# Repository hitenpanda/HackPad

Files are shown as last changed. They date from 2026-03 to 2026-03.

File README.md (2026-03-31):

# HackPad v1

A custom parametric mechanical macropad powered by the Seeed Studio XIAO RP2040. Designed, routed in KiCad, and modeled in Fusion 360 for the Hack Club Blueprint initiative.

## Images
### Overall Look
Overall

### Schematic
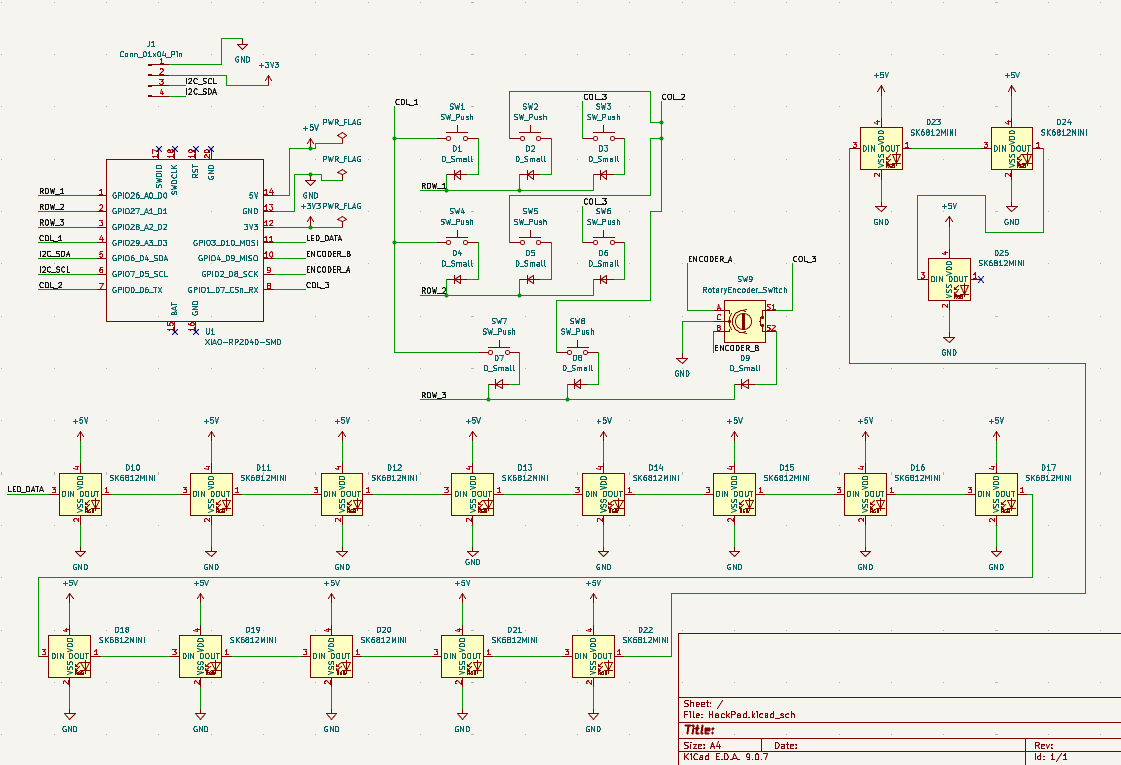
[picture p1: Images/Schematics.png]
Schematic


### PCB
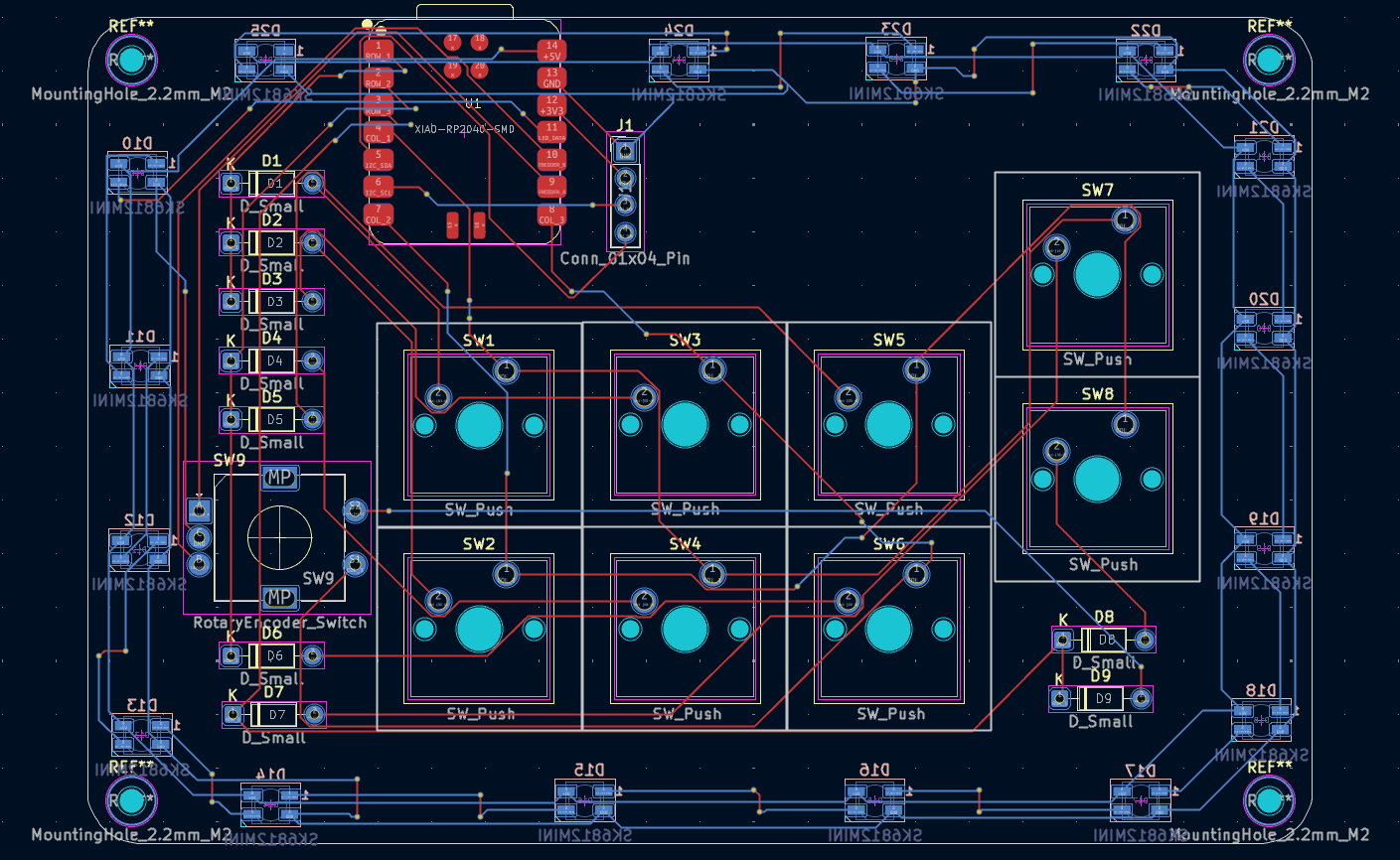
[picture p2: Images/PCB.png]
PCB Layout
 

### Case Assembly
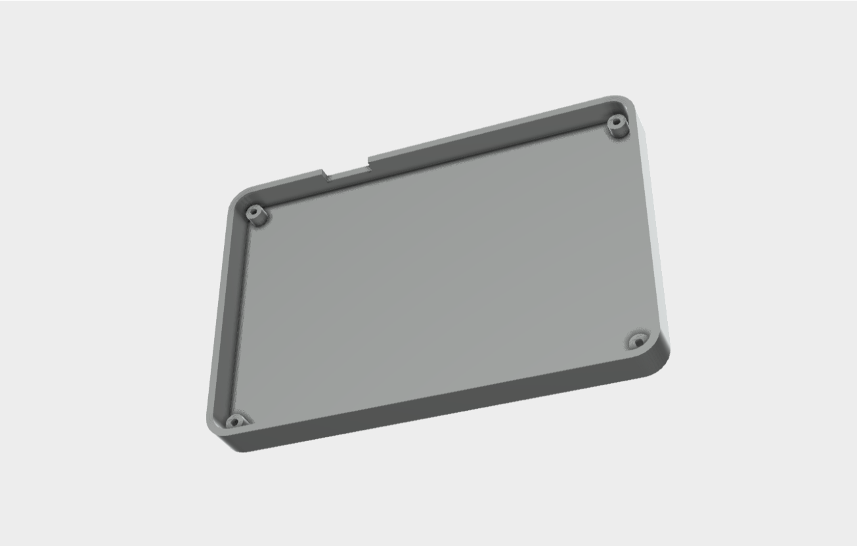
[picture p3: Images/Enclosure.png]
Case Design

*The enclosure is a parametric Lower Tray model built perfectly to fit the PCB outline. It uses a 2.0mm offset, 4.0mm standoffs, and 8.0mm walls for a clean "Floating Key" aesthetic.*

---

## Bill of Materials (BOM)

| Part | Quantity | Description / Notes |
| :--- | :---: | :--- |
| **Seeed Studio XIAO RP2040** | 1 | Main Microcontroller (Through-hole) |
| **Mechanical Switches** | 8 | Kailh Choc V2 switches |
| **Keycaps** | 8 | 1U Keycaps to fit each switch |
| **Custom PCB** | 1 | Custom 2-layer PCB |
| **3D Printed Tray (Bottom)** | 1 | 2.0mm thick base with 8.0mm perimeter walls Translucent |
| **Diodes** | 9 | 1N4148 |
| **Mounting Hardware** | 4 | M2 2.2mm screws for securing PCB to tray standoffs and Heatset inserts |
| **Display** | 1 | 0.91" 128x32 OLED Display |
| **Encoder** | 1 | EC11 Rotary Encoder and 1 x 3D-Printed Knob |

---

## 🛠️ Engineering Log & Design Architecture

To give reviewers insight into the design process, here is the technical breakdown of the hardware environment and enclosure architecture.

### Development Stack
*   **EDA (Electronics):** KiCad 9.0 
*   **MCAD (Mechanics):** Autodesk Fusion 360 

### Mechanical Architecture: The "Tray" Design
The current enclosure is modeled as a **Lower Tray**. The design logic is heavily parametric, ensuring that any future changes to the PCB automatically cascade into the 3D printed enclosure.

*   **The Reference PCB (Global Zero):** The PCB was exported from KiCad as a `.step` file. It serves as the absolute "Global Zero" for all sketch planes. All enclosure components are built on the underside of the board (Negative Z-axis) to ensure pin clearance.
*   **The Chassis Floor:** Traced directly from the PCB outer boundary using a **2.0 mm positive offset**. 
    *   *Fixing the "Swiss Cheese" issue:* Initially, the floor generated as a mess of holes because the switch pin cutouts auto-projected from the PCB. Using Timeline Editing, I re-selected only the inner boundary profiles to generate a clean, solid, dust-proof floor.
*   **The Standoffs (Pillars):** Extruded 4.0 mm up and joined to the chassis floor. This provides crucial clearance for bottom-side solder joints and the XIAO MCU.
*   **The Perimeter Walls:** Originally modeled at 16.0 mm. After performing a physical Stack-up Analysis in CAD (Standoff [4mm] + PCB [1.6mm] + Switch Housing), 16.0 mm caused severe interference. It was parametrically reduced to **8.0 mm**, which perfectly covers the rough PCB edge while leaving the switch housings exposed.

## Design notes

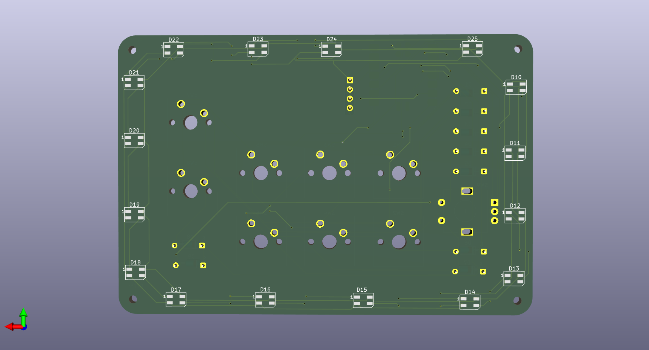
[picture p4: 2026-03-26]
Images/HackPad_Back.png

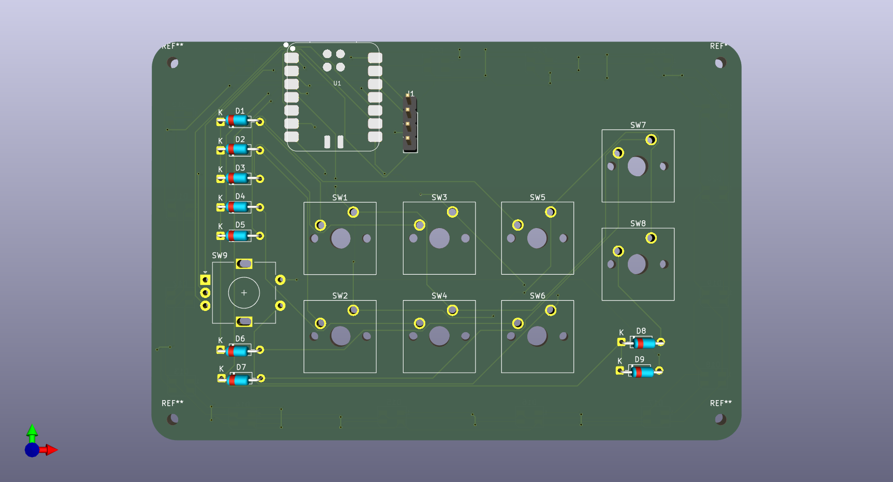
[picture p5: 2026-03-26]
Images/HackPad.png

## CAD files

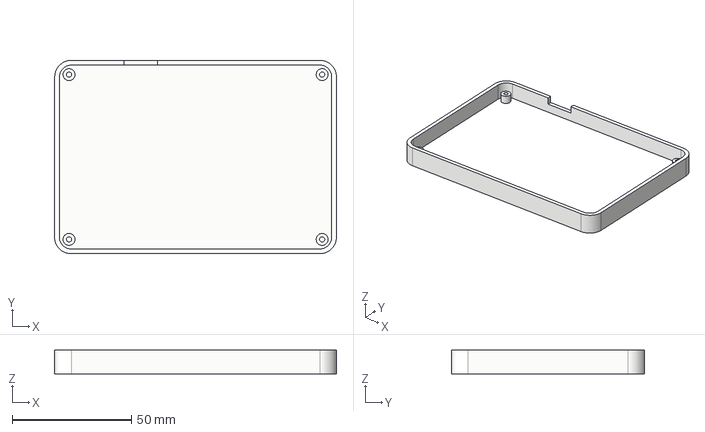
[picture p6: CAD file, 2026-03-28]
CAD/Enclosure/HackPad_Tray_Assembly.step
118.1 x 81.0 x 10.0 mm

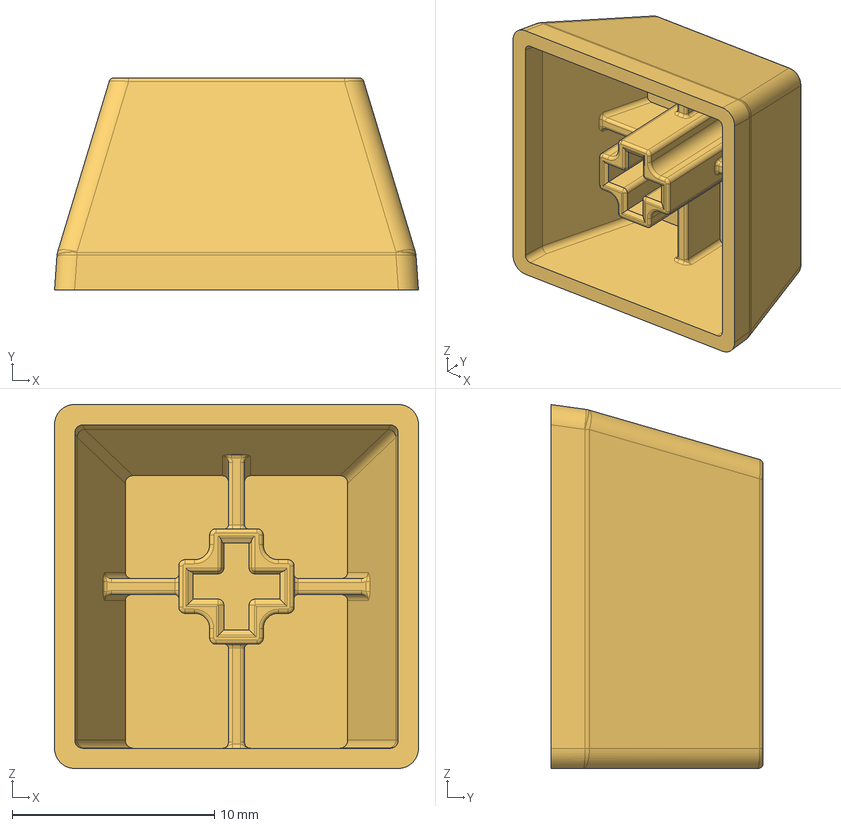
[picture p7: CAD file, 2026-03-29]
CAD/KeyCaps/mx-keycaps.step
18.0 x 10.5 x 18.0 mm

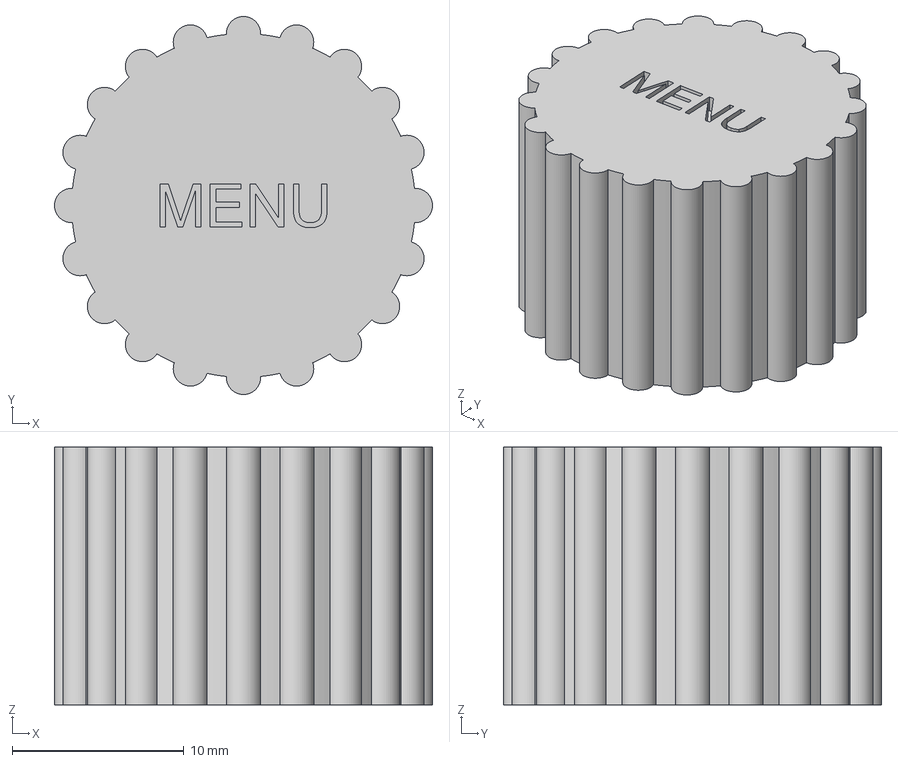
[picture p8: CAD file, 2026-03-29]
CAD/Knob/Knob.step
22.0 x 22.0 x 15.0 mm

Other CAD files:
CAD/Enclosure/BottomCase_Translucent_FILAMENT.stl
Production/Enclosure/BottomCase_Translucent_FILAMENT.stl
CAD/KeyCaps/MX-KEYCAPS.stl
CAD/Knob/Knob.stl
Production/KeyCaps/MX-KEYCAPS.stl
Production/Knob/Knob.stl

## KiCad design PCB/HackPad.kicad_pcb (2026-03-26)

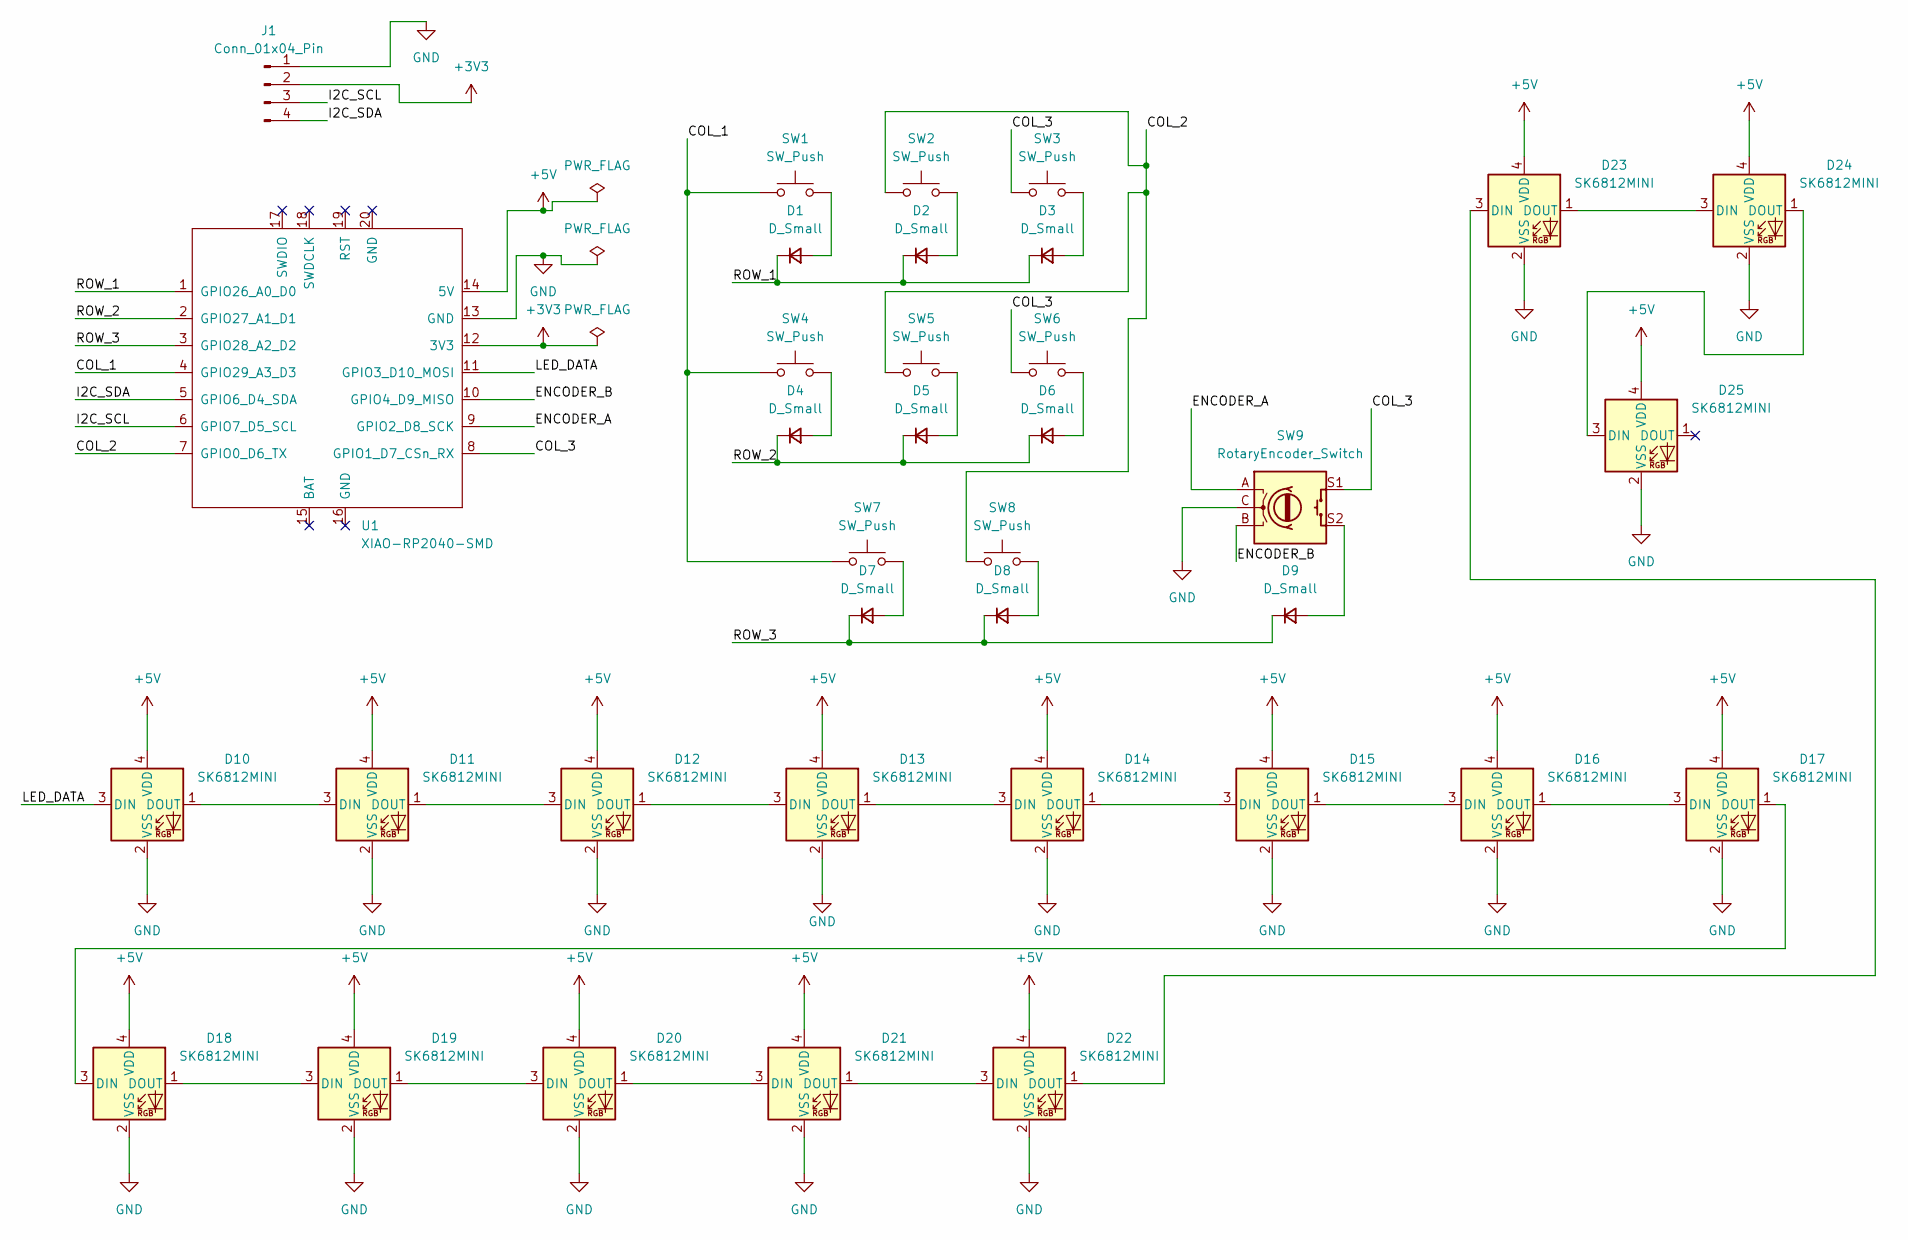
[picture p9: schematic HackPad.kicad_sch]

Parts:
D1, D2, D3, D4, D5, D6, D7, D8, D9: D_Small; D_DO-35_SOD27_P7.62mm_Horizontal
D10, D11, D12, D13, D14, D15, D16, D17, D18, D19, D20, D21, D22, D23, D24, D25: SK6812MINI; LED_SK6812MINI_PLCC4_3.5x3.5mm_P1.75mm
J1: Conn_01x04_Pin; PinHeader_1x04_P2.54mm_Vertical
SW1, SW2, SW3, SW4, SW5, SW6, SW7, SW8: SW_Push; SW_Cherry_MX_1.00u_PCB
SW9: RotaryEncoder_Switch; RotaryEncoder_Alps_EC11E-Switch_Vertical_H20mm
U1: XIAO-RP2040-SMD

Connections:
+3V3: J1.2, U1.12 (3V3)
+5V: D10.4 (VDD), D11.4 (VDD), D12.4 (VDD), D13.4 (VDD), D14.4 (VDD), D15.4 (VDD), D16.4 (VDD), D17.4 (VDD), D18.4 (VDD), D19.4 (VDD), D20.4 (VDD), D21.4 (VDD), D22.4 (VDD), D23.4 (VDD), D24.4 (VDD), D25.4 (VDD), U1.14 (5V)
/COL_1: SW1.1, SW4.1, SW7.1, U1.4 (GPIO29_A3_D3)
/COL_2: SW2.1, SW5.1, SW8.1, U1.7 (GPIO0_D6_TX)
/COL_3: SW3.1, SW6.1, SW9.S1, U1.8 (GPIO1_D7_CSn_RX)
/ENCODER_A: SW9.A, U1.9 (GPIO2_D8_SCK)
/ENCODER_B: SW9.B, U1.10 (GPIO4_D9_MISO)
/I2C_SCL: J1.3, U1.6 (GPIO7_D5_SCL)
/I2C_SDA: J1.4, U1.5 (GPIO6_D4_SDA)
/LED_DATA: D10.3 (DIN), U1.11 (GPIO3_D10_MOSI)
/ROW_1: D1.1 (K), D2.1 (K), D3.1 (K), U1.1 (GPIO26_A0_D0)
/ROW_2: D4.1 (K), D5.1 (K), D6.1 (K), U1.2 (GPIO27_A1_D1)
/ROW_3: D7.1 (K), D8.1 (K), D9.1 (K), U1.3 (GPIO28_A2_D2)
GND: D10.2 (VSS), D11.2 (VSS), D12.2 (VSS), D13.2 (VSS), D14.2 (VSS), D15.2 (VSS), D16.2 (VSS), D17.2 (VSS), D18.2 (VSS), D19.2 (VSS), D20.2 (VSS), D21.2 (VSS), D22.2 (VSS), D23.2 (VSS), D24.2 (VSS), D25.2 (VSS), J1.1, SW9.C, U1.13 (GND)
unnamed: D1.2 (A), SW1.2
unnamed: D2.2 (A), SW2.2
unnamed: D3.2 (A), SW3.2
unnamed: D4.2 (A), SW4.2
unnamed: D5.2 (A), SW5.2
unnamed: D6.2 (A), SW6.2
unnamed: D7.2 (A), SW7.2
unnamed: D8.2 (A), SW8.2
unnamed: D9.2 (A), SW9.S2
unnamed: D10.1 (DOUT), D11.3 (DIN)
unnamed: D11.1 (DOUT), D12.3 (DIN)
unnamed: D12.1 (DOUT), D13.3 (DIN)
unnamed: D13.1 (DOUT), D14.3 (DIN)
unnamed: D14.1 (DOUT), D15.3 (DIN)
unnamed: D15.1 (DOUT), D16.3 (DIN)
unnamed: D16.1 (DOUT), D17.3 (DIN)
unnamed: D17.1 (DOUT), D18.3 (DIN)
unnamed: D18.1 (DOUT), D19.3 (DIN)
unnamed: D19.1 (DOUT), D20.3 (DIN)
unnamed: D20.1 (DOUT), D21.3 (DIN)
unnamed: D21.1 (DOUT), D22.3 (DIN)
unnamed: D22.1 (DOUT), D23.3 (DIN)
unnamed: D23.1 (DOUT), D24.3 (DIN)
unnamed: D24.1 (DOUT), D25.3 (DIN)

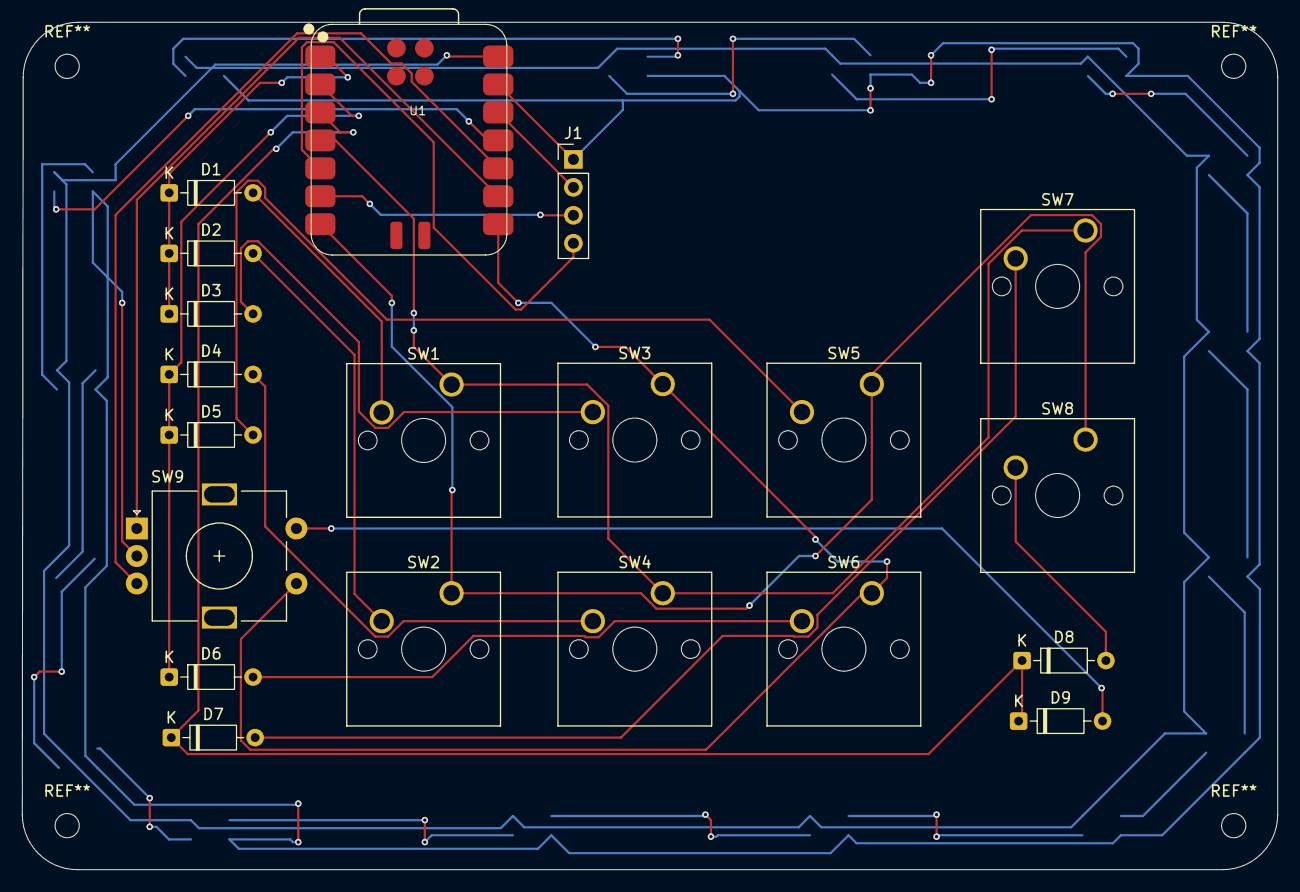
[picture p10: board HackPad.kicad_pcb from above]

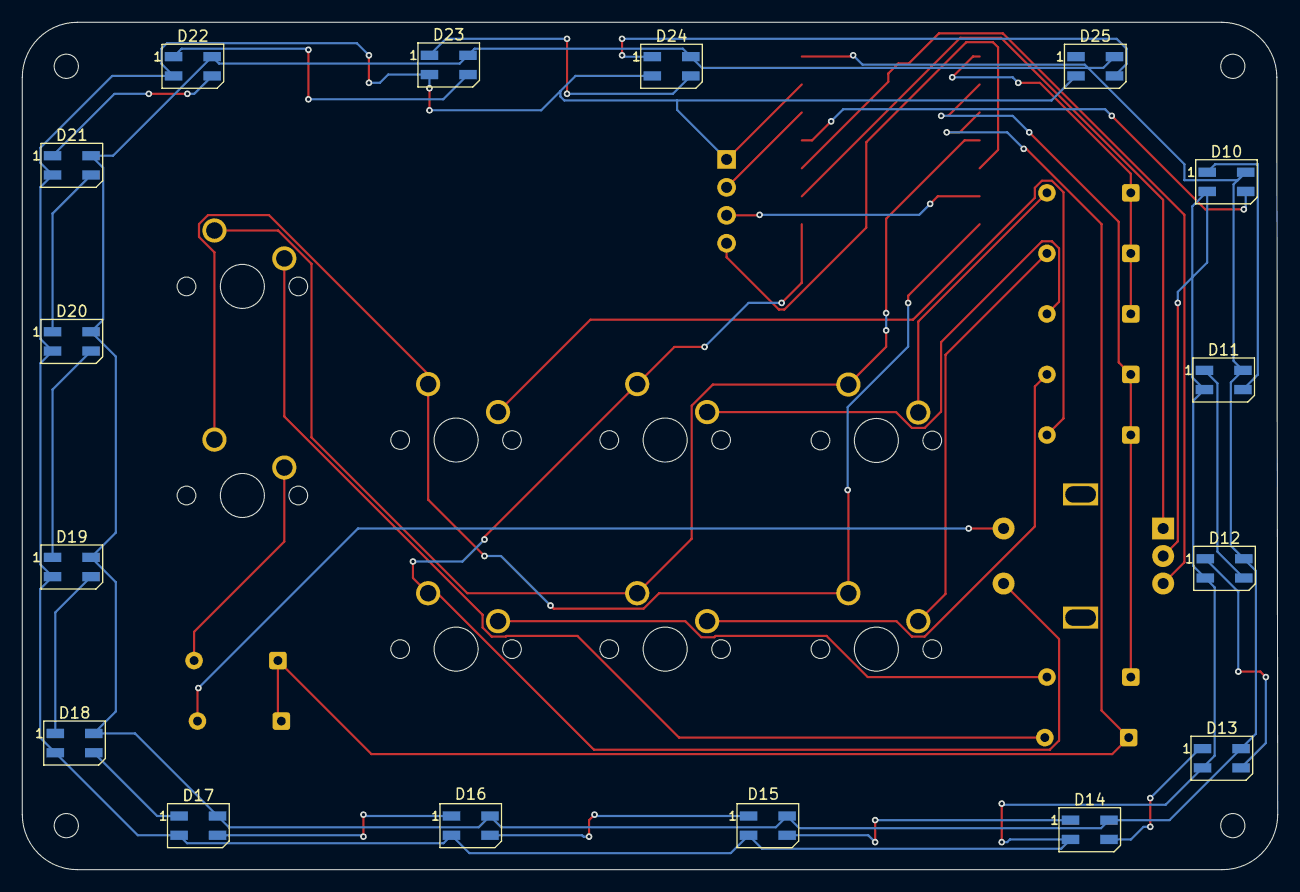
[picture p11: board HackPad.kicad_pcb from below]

Board: 2 copper layers, 114.1 x 77.0 mm, 36 parts (16 on the bottom side), 38 nets.

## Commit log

2026-03-26 Initial commit: Open-source HackPad hardware files and production Gerbers
    [HackPad.kicad_pcb, HackPad.kicad_sch]
2026-03-28 Created 3D Case, only the bottom part. Will be completing it soon.
    [HackPad.f3d, HackPad.step]
2026-03-28 Added the README.md file and corrected the structure.
    [HackPad.f3d]
2026-03-28 Changes: Plan to make a fully closed enclosure dropped, it would be a top naked design.
    [BottomCase_Translucent_FILAMENT.stl, HackPad.f3d, HackPad_Tray_Assembly.step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]
2026-03-29 After some README.md edits and refactoring.
    [HackPad.f3d, HackPadv2.step, HackPadv3.step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]
2026-03-31 The final push for Design Review.
    [BottomCase_Translucent_FILAMENT.stl, HackPad.kicad_pcb, HackPad.kicad_sch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]
